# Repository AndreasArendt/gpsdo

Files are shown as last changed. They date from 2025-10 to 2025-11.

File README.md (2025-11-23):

# GPSDO

**GPSDO** (GPS Disciplined Oscillator) combines the precision of a high-quality OCXO (Oven-Controlled Crystal Oscillator) with the pulse-per-second (PPS) signal from a GNSS receiver. The goal is to achieve accurate time and frequency reference, down to the nanosecond level.

This project aims to create an **open-source and affordable** GPSDO from scratch, including designing custom hardware (PCB) and developing the supporting software.

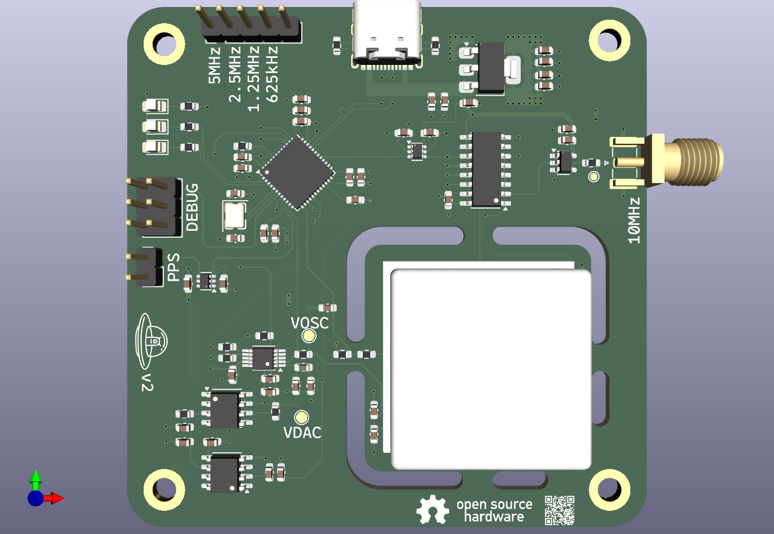
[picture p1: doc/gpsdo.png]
PCB v2 PCB Version 2


# Features
* Combines GNSS PPS with a high-precision OCXO
* Fully open-source hardware and software
* Targeting nanosecond-level timing precision
* Modular design for hardware and software development

# Status
🚧 Under Construction
* The first hardware prototype is currently being tested; all findings are documented in Issue #1
* A Kalman-Filter to estimate `phase`, `frequency_offset` and `frequency_drift` has been implemented
* A PI-Controller is running the GPSDO closed loop
* Flatbuf Messages are implemented to ensure easy-to-extend communication to a host system

# Roadmap
✅ Improve hardware based on findings from V2 prototype  
🔄 Integrate the GNSS receiver on-board for a fully standalone GPSDO  
⚙️ Fine-tune the control loop and filtering algorithms  
📊 Benchmark the true performance against reference standards  

# Contributing
Contributions are welcome! Whether it's hardware design suggestions, software improvements, or analysis scripts, feel free to open an issue or a pull request.

## Compiling flatcc (Windows)
* Navigate into `flatcc` submodule folder.  
* Create `build` folder
* Navigate into `build` folder
* Run `cmake ..`
* Run `cmake --build . --config Release`
* Executable is in `flatcc/bin/Release/flatcc.exe`

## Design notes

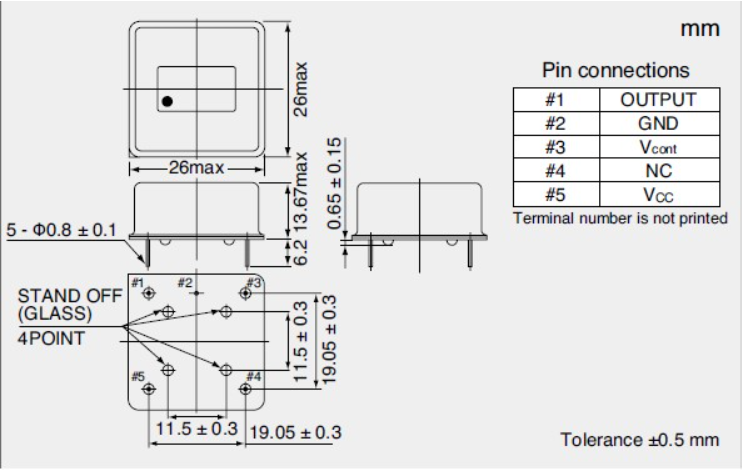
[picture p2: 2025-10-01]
doc/osc5a2b02/dimensions.png

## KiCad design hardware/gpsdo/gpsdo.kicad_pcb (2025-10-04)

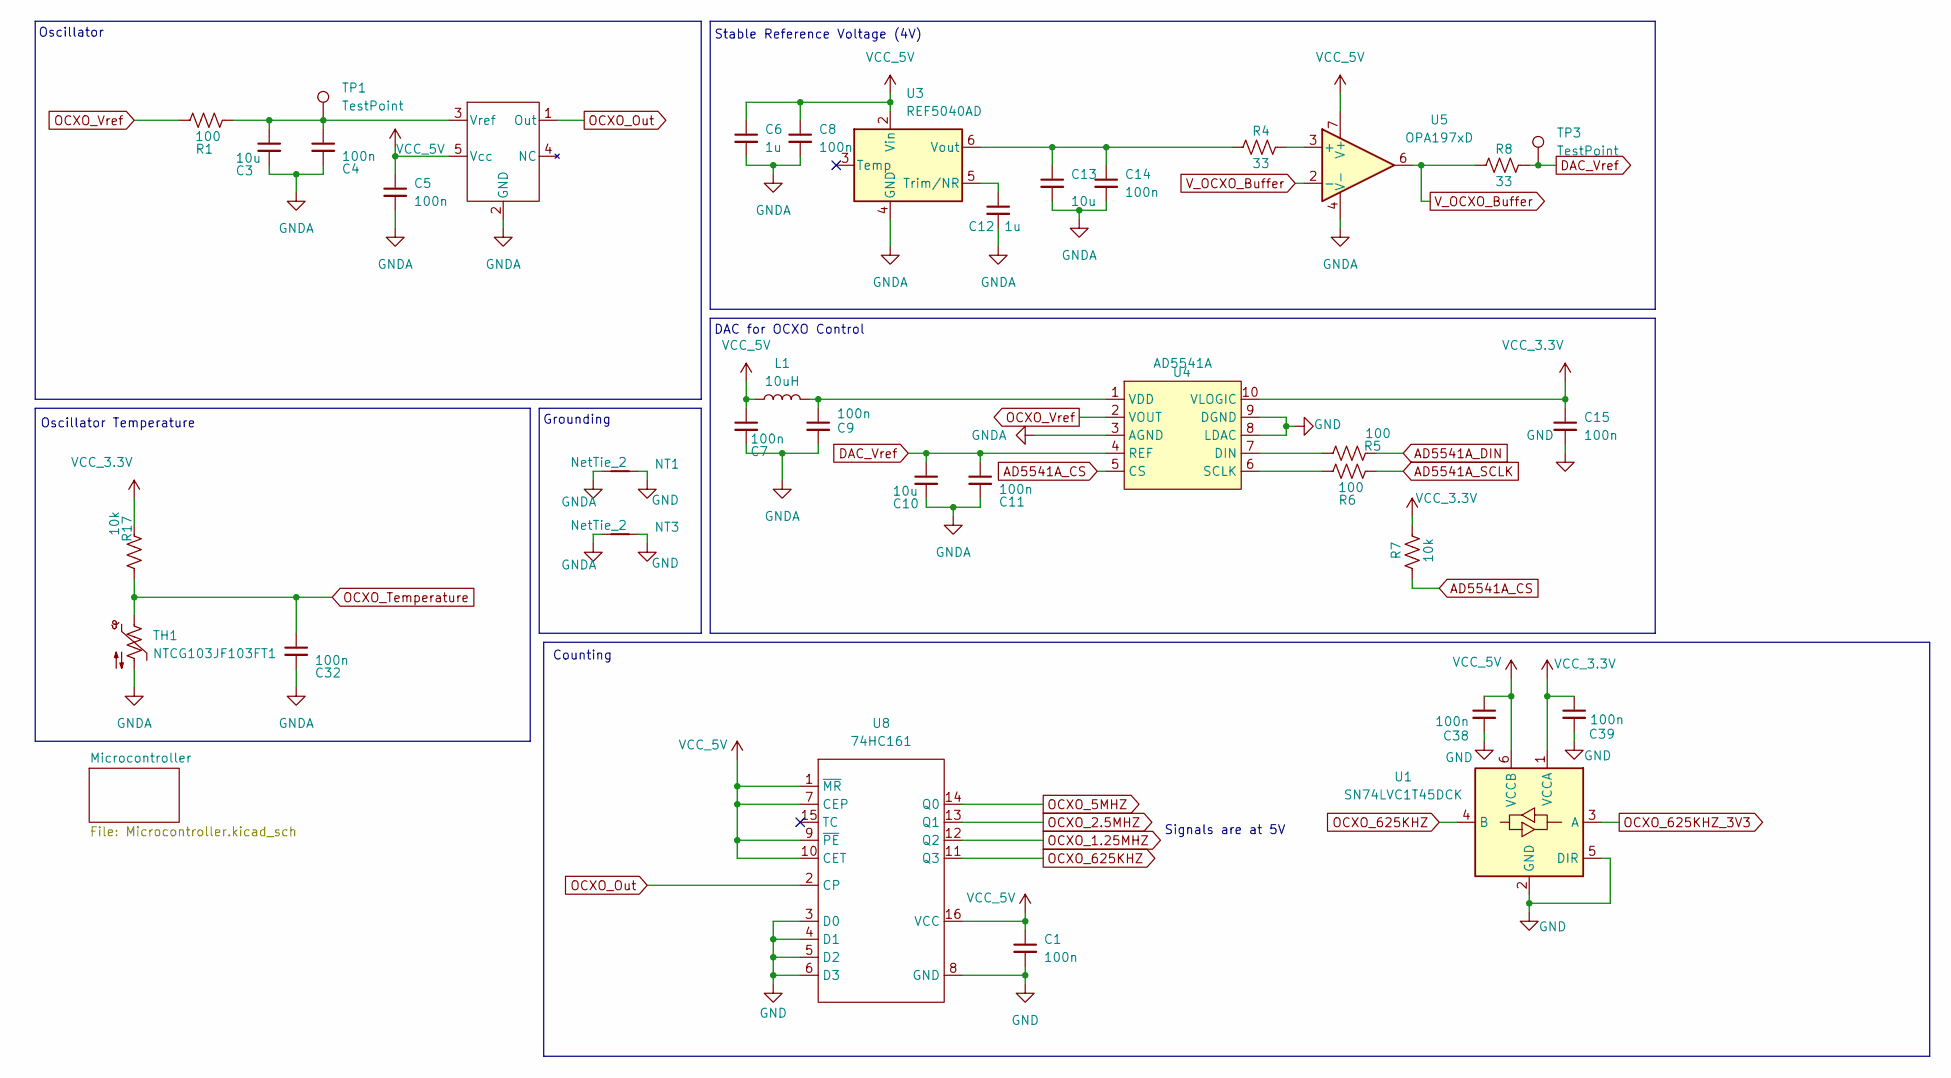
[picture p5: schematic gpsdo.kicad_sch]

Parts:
C1, C4, C5, C7, C8, C9, C11, C14, C15, C32, C38, C39: 100n; C_0603_1608Metric; JLC C14663
C3, C10, C13: 10u; C_0603_1608Metric; JLC C19702
C6, C12: 1u; C_0603_1608Metric; JLC C15849
L1: 10uH; L_0603_1608Metric; JLC C1035
NT1, NT3: NetTie_2; NetTie-2_THT_Pad0.3mm
OSC5A2B1: OSC5A2B02
R1, R5, R6: 100; R_0603_1608Metric; JLC C22775
R4, R8: 33; R_0603_1608Metric; JLC C23140
R7, R17: 10k; R_0603_1608Metric; JLC C25804
TH1: NTCG103JF103FT1; R_0603_1608Metric; JLC C209959
TP1, TP3: TestPoint; TestPoint_Pad_D1.5mm
U1: SN74LVC1T45DCK; SOT-363_SC-70-6; JLC C9382
U3: REF5040AD; SOIC-8_3.9x4.9mm_P1.27mm; JLC C1575304
U4: AD5541A; MSOP-10_3x3mm_P0.5mm; JLC C578210
U5: OPA197xD; SOIC-8_3.9x4.9mm_P1.27mm; JLC C79274
U8: 74HC161; SO-16_3.9x9.9mm_P1.27mm; JLC C22436995

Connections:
AD5541A_CS: R7.1, U4.5 (CS); also elsewhere on the board
AD5541A_DIN: R5.2; also elsewhere on the board
AD5541A_SCLK: R6.2; also elsewhere on the board
DAC_Vref: C10.1, C11.1, R8.2, TP3.1, U4.4 (REF)
GND: C1.2, C15.2, C38.2, C39.2, NT1.2, NT3.2, U1.2 (GND), U1.5 (DIR), U4.8 (LDAC), U4.9 (DGND), U8.3 (D0), U8.4 (D1), U8.5 (D2), U8.6 (D3), U8.8 (GND); also elsewhere on the board
GNDA: C3.2, C4.2, C5.2, C6.2, C7.2, C8.2, C9.2, C10.2, C11.2, C12.2, C13.2, C14.2, C32.2, NT1.1, NT3.1, OSC5A2B1.2 (GND), TH1.2, U3.4 (GND), U4.3 (AGND), U5.4 (V-); also elsewhere on the board
unnamed: C3.1, C4.1, OSC5A2B1.3 (Vref), R1.2, TP1.1
unnamed: C12.1, U3.5 (Trim/NR)
unnamed: C13.1, C14.1, R4.1, U3.6 (Vout)
unnamed: R5.1, U4.7 (DIN)
unnamed: R6.1, U4.6 (SCLK)
unnamed: C9.1, L1.2, U4.1 (VDD)
unnamed: R4.2, U5.3 (+)
OCXO_1.25MHZ: U8.12 (Q2); also elsewhere on the board
OCXO_2.5MHZ: U8.13 (Q1); also elsewhere on the board
OCXO_5MHZ: U8.14 (Q0); also elsewhere on the board
OCXO_625KHZ: U1.4 (B), U8.11 (Q3); also elsewhere on the board
OCXO_625KHZ_3V3: U1.3 (A); also elsewhere on the board
OCXO_Out: OSC5A2B1.1 (Out), U8.2 (CP); also elsewhere on the board
OCXO_Temperature: C32.1, R17.1, TH1.1; also elsewhere on the board
OCXO_Vref: R1.1, U4.2 (VOUT); also elsewhere on the board
VCC_5V: C1.1, C5.1, C6.1, C7.1, C8.1, C38.1, L1.1, OSC5A2B1.5 (Vcc), U1.6 (VCCB), U3.2 (Vin), U5.7 (V+), U8.1 (~MR), U8.7 (CEP), U8.9 (~PE), U8.10 (CET), U8.16 (VCC); also elsewhere on the board
VDD_3V3: C15.1, C39.1, R7.2, R17.2, U1.1 (VCCA), U4.10 (VLOGIC); also elsewhere on the board
V_OCXO_Buffer: R8.1, U5.2 (-), U5.6

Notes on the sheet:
Oscillator Temperature
Grounding
Stable Reference Voltage (4V)
Counting
Oscillator
DAC for OCXO Control
Signals are at 5V

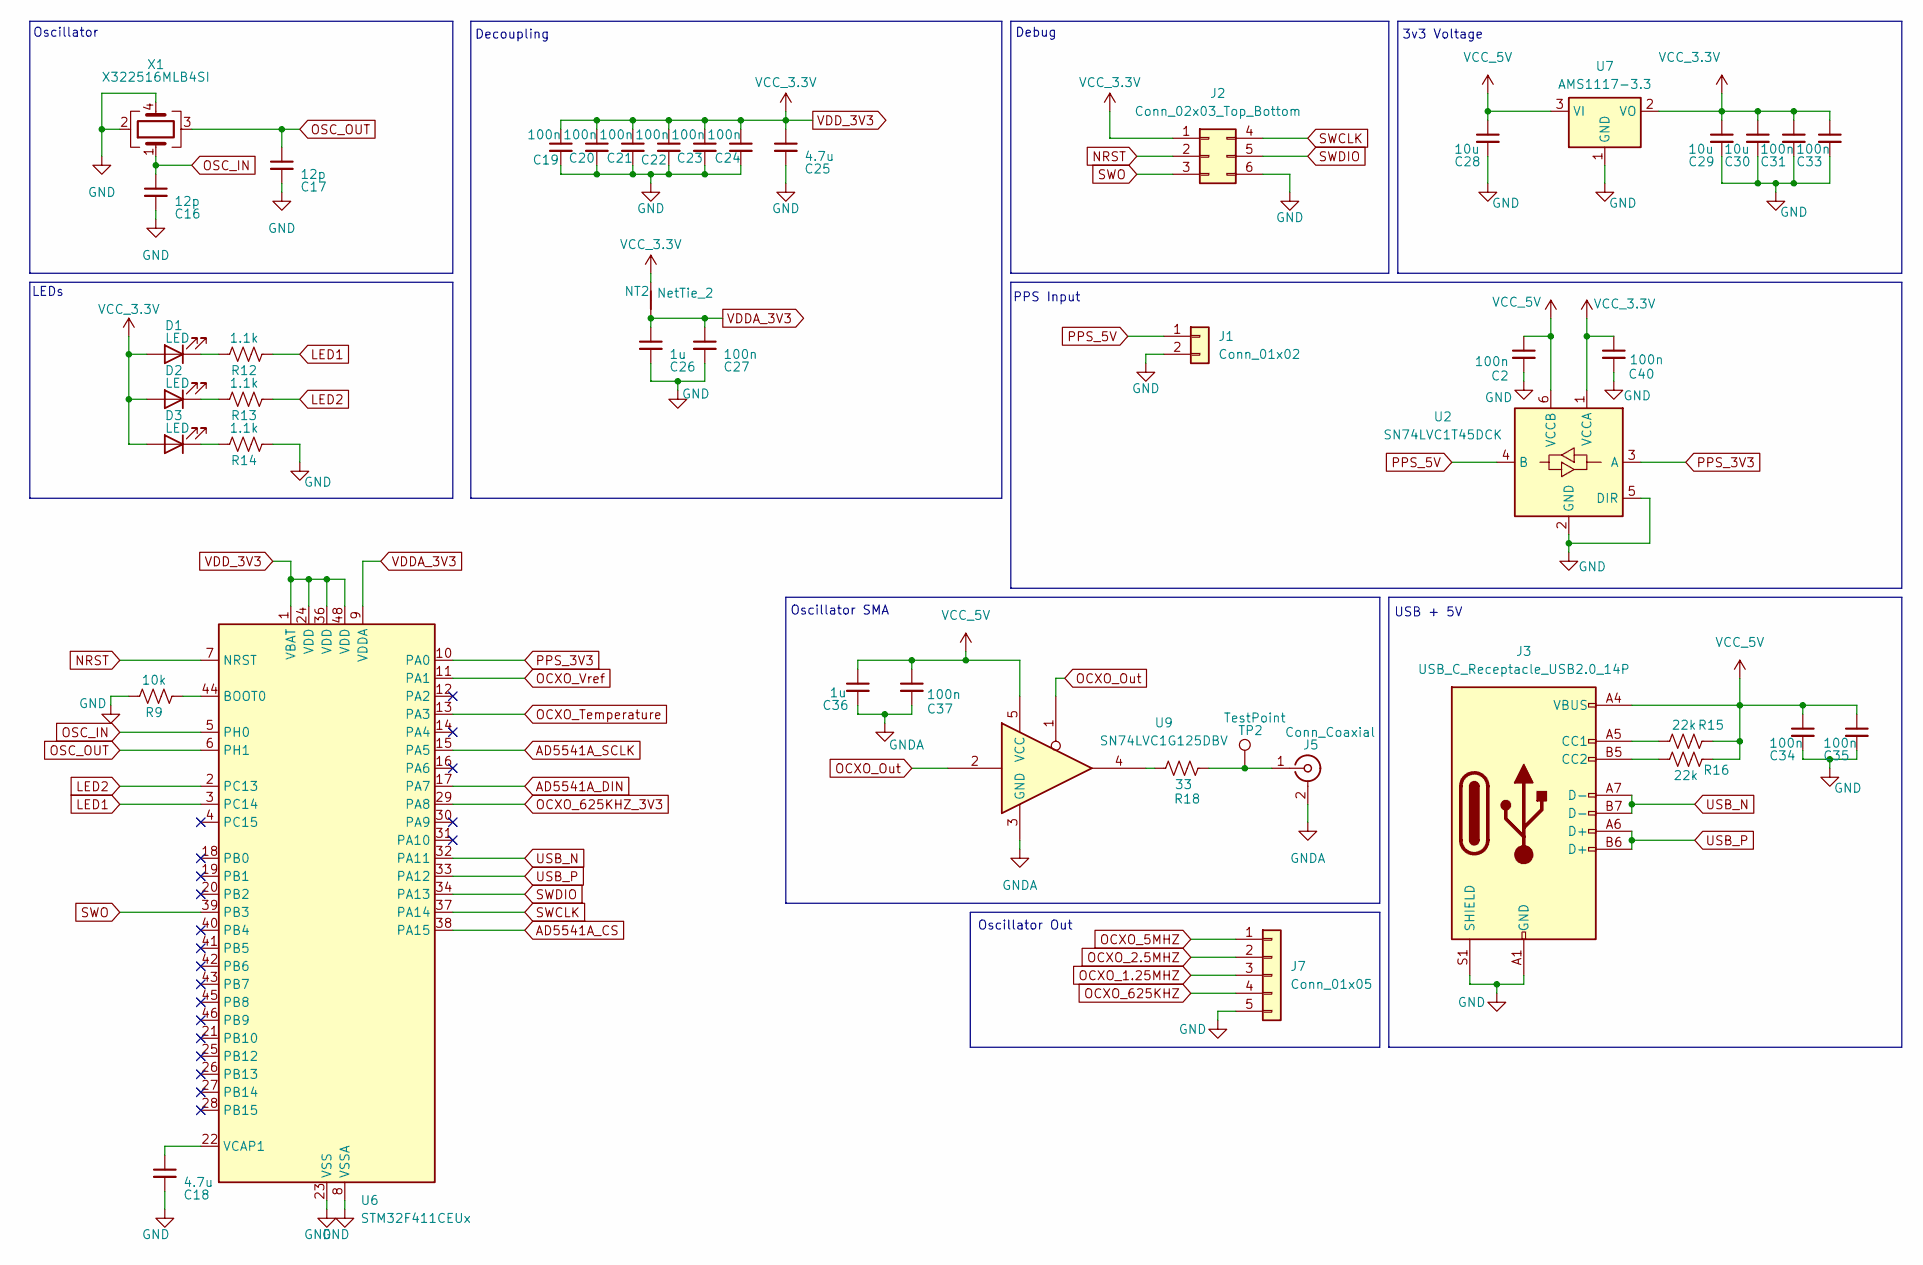
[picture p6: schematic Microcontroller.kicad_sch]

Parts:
C2, C19, C20, C21, C22, C23, C24, C27, C31, C33, C34, C35, C37, C40: 100n; C_0603_1608Metric; JLC C14663
C16, C17: 12p; C_0603_1608Metric; JLC C38523
C18, C25: 4.7u; C_0603_1608Metric; JLC C19666
C26, C36: 1u; C_0603_1608Metric; JLC C15849
C28, C29, C30: 10u; C_0603_1608Metric; JLC C19702
D1: LED; LED_0805_2012Metric_Pad1.15x1.40mm_HandSolder; JLC C2296
D2: LED; LED_0805_2012Metric_Pad1.15x1.40mm_HandSolder; JLC C84256
D3: LED; LED_0805_2012Metric_Pad1.15x1.40mm_HandSolder; JLC C2297
J1: Conn_01x02; PinHeader_1x02_P2.54mm_Vertical
J2: Conn_02x03_Top_Bottom; PinHeader_2x03_P2.54mm_Vertical
J3: USB_C_Receptacle_USB2.0_14P; USB_C_Receptacle_G-Switch_GT-USB-7010ASV; JLC C2988369
J5: Conn_Coaxial; SMA_Samtec_SMA-J-P-H-ST-EM1_EdgeMount; JLC C914558
J7: Conn_01x05; PinHeader_1x05_P2.54mm_Vertical
NT2: NetTie_2; NetTie-2_THT_Pad0.3mm
R9: 10k; R_0603_1608Metric; JLC C25804
R12, R13, R14: 1.1k; R_0603_1608Metric; JLC C17375
R15, R16: 22k; R_0603_1608Metric; JLC C31850
R18: 33; R_0603_1608Metric; JLC C23140
TP2: TestPoint; TestPoint_Pad_D1.0mm
U2: SN74LVC1T45DCK; SOT-363_SC-70-6; JLC C9382
U6: STM32F411CEUx; QFN-48-1EP_7x7mm_P0.5mm_EP5.6x5.6mm; JLC C60420
U7: AMS1117-3.3; SOT-223-3_TabPin2; JLC C347222
U9: SN74LVC1G125DBV; SOT-23-5; JLC C23654
X1: X322516MLB4SI; Crystal_SMD_3225-4Pin_3.2x2.5mm; JLC C13738

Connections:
AD5541A_CS: U6.38 (PA15); also elsewhere on the board
AD5541A_DIN: U6.17 (PA7); also elsewhere on the board
AD5541A_SCLK: U6.15 (PA5); also elsewhere on the board
GND: C2.2, C16.2, C17.2, C18.2, C19.2, C20.2, C21.2, C22.2, C23.2, C24.2, C25.2, C26.2, C27.2, C28.2, C29.2, C30.2, C31.2, C33.2, C34.2, C35.2, C40.2, J1.2, J2.6, J3.A1 (GND), J3.A12 (GND), J3.B1 (GND), J3.B12 (GND), J3.S1 (SHIELD), J7.5, R9.2, R14.1, U2.2 (GND), U2.5 (DIR), U6.8 (VSSA), U6.23 (VSS), U6.35 (VSS), U6.47 (VSS), U6.49 (VSS), U7.1 (GND), X1.2, X1.4; also elsewhere on the board
GNDA: C36.2, C37.2, J5.2 (Ext), U9.3 (GND); also elsewhere on the board
LED1: R12.1, U6.3 (PC14)
LED2: R13.1, U6.2 (PC13)
NRST: J2.2, U6.7 (NRST)
unnamed: D1.1 (K), R12.2
unnamed: D2.1 (K), R13.2
unnamed: D3.1 (K), R14.2
unnamed: J3.A5 (CC1), R15.2
unnamed: J3.B5 (CC2), R16.2
unnamed: J5.1 (In), R18.1, TP2.1
unnamed: R18.2, U9.4
unnamed: R9.1, U6.44 (BOOT0)
unnamed: C18.1, U6.22 (VCAP1)
OCXO_1.25MHZ: J7.3; also elsewhere on the board
OCXO_2.5MHZ: J7.2; also elsewhere on the board
OCXO_5MHZ: J7.1; also elsewhere on the board
OCXO_625KHZ: J7.4; also elsewhere on the board
OCXO_625KHZ_3V3: U6.29 (PA8); also elsewhere on the board
OCXO_Out: U9.1, U9.2; also elsewhere on the board
OCXO_Temperature: U6.13 (PA3); also elsewhere on the board
OCXO_Vref: U6.11 (PA1); also elsewhere on the board
OSC_IN: C16.1, U6.5 (PH0), X1.1
OSC_OUT: C17.1, U6.6 (PH1), X1.3
PPS_3V3: U2.3 (A), U6.10 (PA0)
PPS_5V: J1.1, U2.4 (B)
SWCLK: J2.4, U6.37 (PA14)
SWDIO: J2.5, U6.34 (PA13)
SWO: J2.3, U6.39 (PB3)
USB_N: J3.A7 (D-), J3.B7 (D-), U6.32 (PA11)
USB_P: J3.A6 (D+), J3.B6 (D+), U6.33 (PA12)
VCC_5V: C2.1, C28.1, C34.1, C35.1, C36.1, C37.1, J3.A4 (VBUS), J3.A9 (VBUS), J3.B4 (VBUS), J3.B9 (VBUS), R15.1, R16.1, U2.6 (VCCB), U7.3 (VI), U9.5 (VCC); also elsewhere on the board
VDDA_3V3: C26.1, C27.1, NT2.1, U6.9 (VDDA)
VDD_3V3: C19.1, C20.1, C21.1, C22.1, C23.1, C24.1, C25.1, C29.1, C30.1, C31.1, C33.1, C40.1, D1.2 (A), D2.2 (A), D3.2 (A), J2.1, NT2.2, U2.1 (VCCA), U6.1 (VBAT), U6.24 (VDD), U6.36 (VDD), U6.48 (VDD), U7.2 (VO); also elsewhere on the board

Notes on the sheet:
Oscillator Out
Debug
PPS Input
LEDs
USB + 5V
Oscillator SMA
Decoupling
3v3 Voltage
Oscillator

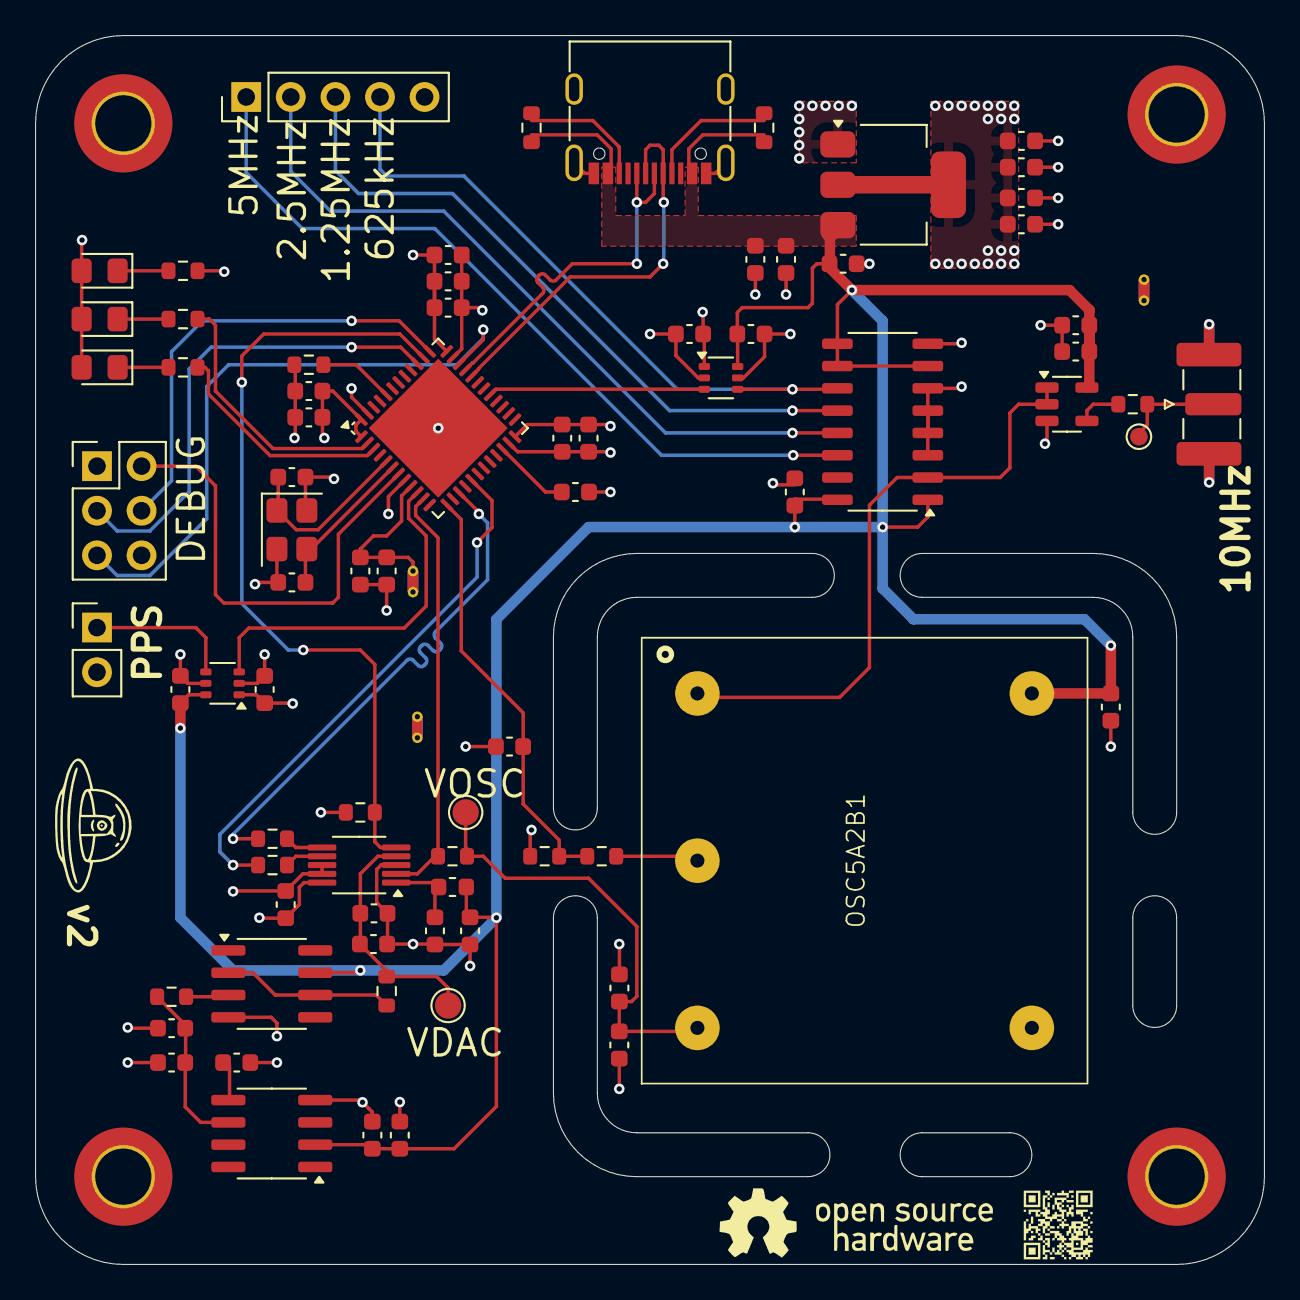
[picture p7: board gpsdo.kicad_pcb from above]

Board: 4 copper layers, 70.0 x 70.0 mm, 81 parts (0 on the bottom side), 46 nets.

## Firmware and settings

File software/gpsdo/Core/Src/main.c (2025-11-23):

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
/* Includes ------------------------------------------------------------------*/
#include "main.h"
#include "cmsis_os.h"
#include "usb_device.h"

/* USER CODE BEGIN Includes */
#include "pps.h"
#include "usb.h"
#include "led.h"
#include "hal.h"
/* USER CODE END Includes */

typedef StaticTask_t osStaticThreadDef_t;
typedef StaticSemaphore_t osStaticSemaphoreDef_t;
ADC_HandleTypeDef hadc1;
DMA_HandleTypeDef hdma_adc1;

SPI_HandleTypeDef hspi1;

TIM_HandleTypeDef htim1;
TIM_HandleTypeDef htim2;
TIM_HandleTypeDef htim5;

/* Definitions for tsk_controller */
osThreadId_t tsk_controllerHandle;
uint32_t controllerTaskBuffer[ 2048 ];
osStaticThreadDef_t controllerTaskControlBlock;
const osThreadAttr_t tsk_controller_attributes = {
  .name = "tsk_controller",
  .cb_mem = &controllerTaskControlBlock,
  .cb_size = sizeof(controllerTaskControlBlock),
  .stack_mem = &controllerTaskBuffer[0],
  .stack_size = sizeof(controllerTaskBuffer),
  .priority = (osPriority_t) osPriorityNormal,
};
/* Definitions for tsk_usb */
osThreadId_t tsk_usbHandle;
uint32_t usbTaskBuffer[ 2048 ];
osStaticThreadDef_t usbTaskControlBlock;
const osThreadAttr_t tsk_usb_attributes = {
  .name = "tsk_usb",
  .cb_mem = &usbTaskControlBlock,
  .cb_size = sizeof(usbTaskControlBlock),
  .stack_mem = &usbTaskBuffer[0],
  .stack_size = sizeof(usbTaskBuffer),
  .priority = (osPriority_t) osPriorityLow,
};
/* Definitions for tsk_manager */
osThreadId_t tsk_managerHandle;
uint32_t tsk_managerBuffer[ 256 ];
osStaticThreadDef_t tsk_managerControlBlock;
const osThreadAttr_t tsk_manager_attributes = {
  .name = "tsk_manager",
  .cb_mem = &tsk_managerControlBlock,
  .cb_size = sizeof(tsk_managerControlBlock),
  .stack_mem = &tsk_managerBuffer[0],
  .stack_size = sizeof(tsk_managerBuffer),
  .priority = (osPriority_t) osPriorityLow,
};
/* Definitions for xPPSSemaphore */
osSemaphoreId_t xPPSSemaphoreHandle;
osStaticSemaphoreDef_t xPPSSemaphoreControlBlock;
const osSemaphoreAttr_t xPPSSemaphore_attributes = {
  .name = "xPPSSemaphore",
  .cb_mem = &xPPSSemaphoreControlBlock,
  .cb_size = sizeof(xPPSSemaphoreControlBlock),
};
/* USER CODE BEGIN PV */
/* Definitions for sem_IMUdataReceived */
/* USER CODE END PV */

void SystemClock_Config(void);
static void MX_GPIO_Init(void);
static void MX_DMA_Init(void);
static void MX_TIM1_Init(void);
static void MX_TIM5_Init(void);
static void MX_ADC1_Init(void);
static void MX_TIM2_Init(void);
static void MX_SPI1_Init(void);
void controllerTask(void *argument);
void usbTask(void *argument);
void mangerTask(void *argument);

/* USER CODE BEGIN PFP */
uint8_t hal_initialized = 0;
/* USER CODE END PFP */

/* USER CODE BEGIN 0 */
uint16_t adc_dma_buffer[2];  // CH1, CH3
/* USER CODE END 0 */

/**
  * @brief  The application entry point.
  * @retval int
  */
int main(void)
{

  /* MCU Configuration--------------------------------------------------------*/

  /* Reset of all peripherals, Initializes the Flash interface and the Systick. */
  HAL_Init();

  /* Configure the system clock */
  SystemClock_Config();

  /* Initialize all configured peripherals */
  MX_GPIO_Init();
  MX_DMA_Init();
  MX_TIM1_Init();
  MX_TIM5_Init();
  MX_ADC1_Init();
  MX_TIM2_Init();
  MX_SPI1_Init();
  /* USER CODE BEGIN 2 */
	usb_init();

	HAL_NVIC_DisableIRQ(DMA2_Stream0_IRQn);  // disable ADC1 DMA interrupt
	HAL_ADC_Start_DMA(&hadc1, (uint32_t*) adc_dma_buffer, 2);

	reset_led_orange();
	reset_led_red();

  /* USER CODE END 2 */

  /* Init scheduler */
  osKernelInitialize();

  /* USER CODE BEGIN RTOS_MUTEX */
	/* add mutexes, ... */
  /* USER CODE END RTOS_MUTEX */

  /* Create the semaphores(s) */
  /* creation of xPPSSemaphore */
  xPPSSemaphoreHandle = osSemaphoreNew(1, 0, &xPPSSemaphore_attributes);

  /* USER CODE BEGIN RTOS_SEMAPHORES */
	/* add semaphores, ... */
  /* USER CODE END RTOS_SEMAPHORES */

  /* USER CODE BEGIN RTOS_TIMERS */
	/* start timers, add new ones, ... */
  /* USER CODE END RTOS_TIMERS */

  /* USER CODE BEGIN RTOS_QUEUES */
	/* add queues, ... */
  /* USER CODE END RTOS_QUEUES */

  /* Create the thread(s) */
  /* creation of tsk_controller */
  tsk_controllerHandle = osThreadNew(controllerTask, NULL, &tsk_controller_attributes);

  /* creation of tsk_usb */
  tsk_usbHandle = osThreadNew(usbTask, NULL, &tsk_usb_attributes);

  /* creation of tsk_manager */
  tsk_managerHandle = osThreadNew(mangerTask, NULL, &tsk_manager_attributes);

  /* USER CODE BEGIN RTOS_THREADS */
	/* add threads, ... */
  /* USER CODE END RTOS_THREADS */

  /* USER CODE BEGIN RTOS_EVENTS */
	/* add events, ... */
  /* USER CODE END RTOS_EVENTS */

  /* Start scheduler */
  osKernelStart();

  /* We should never get here as control is now taken by the scheduler */

  /* Infinite loop */
  /* USER CODE BEGIN WHILE */
	while (1) {

    /* USER CODE END WHILE */

    /* USER CODE BEGIN 3 */
	}
  /* USER CODE END 3 */
}

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
/* USER CODE BEGIN Header_controllerTask */
/**
 * @brief  Function implementing the tsk_controllerT thread.
 * @param  argument: Not used
 * @retval None
 */
/* USER CODE END Header_controllerTask */
__weak void controllerTask(void *argument)
{
  /* init code for USB_DEVICE */
  MX_USB_DEVICE_Init();
  /* USER CODE BEGIN 5 */
	/* Infinite loop */
	for (;;) {
		osDelay(1);
	}
  /* USER CODE END 5 */
}

/* USER CODE BEGIN Header_usbTask */
/**
 * @brief Function implementing the tsk_usb thread.
 * @param argument: Not used
 * @retval None
 */
/* USER CODE END Header_usbTask */
__weak void usbTask(void *argument)
{
  /* USER CODE BEGIN usbTask */
	/* Infinite loop */
	for (;;) {
		osDelay(1);
	}
  /* USER CODE END usbTask */
}

/* USER CODE BEGIN Header_mangerTask */
/**
 * @brief Function implementing the tsk_manager thread.
 * @param argument: Not used
 * @retval None
 */
/* USER CODE END Header_mangerTask */
__weak void mangerTask(void *argument)
{
  /* USER CODE BEGIN mangerTask */
	/* Infinite loop */
	for (;;) {
		osDelay(1);
	}
  /* USER CODE END mangerTask */
}

/**
  * @brief  Period elapsed callback in non blocking mode
  * @note   This function is called  when TIM4 interrupt took place, inside
  * HAL_TIM_IRQHandler(). It makes a direct call to HAL_IncTick() to increment
  * a global variable "uwTick" used as application time base.
  * @param  htim : TIM handle
  * @retval None
  */
void HAL_TIM_PeriodElapsedCallback(TIM_HandleTypeDef *htim)
{
  if (htim->Instance == TIM4)
  {
    HAL_IncTick();
  }
}

/**
  * @brief  This function is executed in case of error occurrence.
  * @retval None
  */
void Error_Handler(void)
{
  /* USER CODE BEGIN Error_Handler_Debug */
	/* User can add his own implementation to report the HAL error return state */
	__disable_irq();
	while (1) {
	}
  /* USER CODE END Error_Handler_Debug */
}
#ifdef USE_FULL_ASSERT
/**
  * @brief  Reports the name of the source file and the source line number
  *         where the assert_param error has occurred.
  * @param  file: pointer to the source file name
  * @param  line: assert_param error line source number
  * @retval None
  */
void assert_failed(uint8_t *file, uint32_t line)
{
  /* USER CODE BEGIN 6 */
  /* User can add his own implementation to report the file name and line number,
     ex: printf("Wrong parameters value: file %s on line %d\r\n", file, line) */
  /* USER CODE END 6 */
}
#endif /* USE_FULL_ASSERT */

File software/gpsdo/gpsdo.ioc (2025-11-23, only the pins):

Mcu.UserName=STM32F411CEUx
PA0-WKUP.Signal=S_TIM5_CH1
PA1.Signal=ADCx_IN1
PA11.Signal=USB_OTG_FS_DM
PA12.Signal=USB_OTG_FS_DP
PA13.Signal=SYS_JTMS-SWDIO
PA14.Signal=SYS_JTCK-SWCLK
PA15.Signal=GPIO_Output
PA3.Signal=ADCx_IN3
PA5.Signal=SPI1_SCK
PA7.Signal=SPI1_MOSI
PA8.Signal=S_TIM1_CH1
PB3.Signal=SYS_JTDO-SWO
PC13-ANTI_TAMP.Signal=GPIO_Output
PC14-OSC32_IN.Signal=GPIO_Output

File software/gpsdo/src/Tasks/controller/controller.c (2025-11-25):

#include "controller.h"
#include "hal.h"
#include "led.h"
#include "filter.h"
#include "pps.h"
#include "flatbuf_message_builder.h"
#include "manager.h"
#include "gpsdo_config.h"

#include <math.h>
#include <stdbool.h>

#define DAC_CS_Pin GPIO_PIN_15
#define DAC_CS_GPIO_Port GPIOA

#define DAC_SYNC_PORT GPIOA
#define DAC_SYNC_PIN GPIO_PIN_15

static const float Kp = 0.0025f;
static const float Ki = 0.00001f;
static const float Kd = 0.0f;

static KF_DebugSnapshot kf_debug = { 0 };

void DAC_Select() {
	HAL_GPIO_WritePin(DAC_CS_GPIO_Port, DAC_CS_Pin, GPIO_PIN_RESET);
}
void DAC_Unselect() {
	HAL_GPIO_WritePin(DAC_CS_GPIO_Port, DAC_CS_Pin, GPIO_PIN_SET);
}

void DAC_AD5541A_set_value(uint16_t value) {
	if (value >= 48000)
		return;

	uint8_t txData[2];

	// Split into bytes (MSB first)
	txData[0] = (value >> 8) & 0xFF;
	txData[1] = value & 0xFF;

	// Latch sequence
	HAL_GPIO_WritePin(DAC_SYNC_PORT, DAC_SYNC_PIN, GPIO_PIN_RESET);
	__NOP();
	__NOP();
	HAL_SPI_Transmit(&hspi1, txData, 2, HAL_MAX_DELAY);
	__NOP();
	__NOP();
	HAL_GPIO_WritePin(DAC_SYNC_PORT, DAC_SYNC_PIN, GPIO_PIN_SET);
}

void DAC_SetVoltage(float voltage) {
	// Clamp and scale
	if (voltage < V_Min)
		voltage = V_Min;
	if (voltage > V_Max)
		voltage = V_Max;

	uint16_t value = (uint16_t) roundf((voltage / DAC_VREF) * 65535.0f);
	DAC_AD5541A_set_value(value);
}

float control(float phase_cnt, float freq_offset, float freq_drift) {
	float p = Kp * freq_offset;
	float i = Ki * phase_cnt;
	float d = Kd * freq_drift;

	float v_out = V_Mid + p + i + d;

	// clamping
	if (v_out > V_Max)
		v_out = V_Max;
	if (v_out < V_Min)
		v_out = V_Min;

	return v_out;
}

float controller_ema(float val, float prev, float alpha) {
	return alpha * val + (1 - alpha) * prev;
}

void controllerTask(void *argument) {
	while (!hal_initialized)
		osDelay(100);

	static float volt = V_Mid;
	static float freq_drift_HzDs_prev = 0.0f, prev_phase = 0.0f, prev_freq = 0.0f;
	static bool first_run = true;

	filter_init();
	DAC_SetVoltage(volt);

	while (1) {
		osSemaphoreAcquire(xPPSSemaphoreHandle, osWaitForever);
		toggle_led_orange();
		uint32_t delta = pps_get_delta();

		filter_step(delta, volt);
		float phase_cnt = filter_get_phase_count();
		float freq_off_Hz = filter_get_frequency_offset_Hz();
		float freq_drift_HzDs = filter_get_frequency_drift_HzDs();

		// ema smoothing
		if(first_run)
			first_run = false;
		else
		{
			phase_cnt = controller_ema(phase_cnt, prev_phase, 0.02);       // 50 s
			freq_off_Hz = controller_ema(freq_off_Hz, prev_freq, 0.01);    // 100 s
			freq_drift_HzDs = controller_ema(freq_drift_HzDs, freq_drift_HzDs_prev, 0.001); // 1000s
		}

		freq_drift_HzDs_prev = freq_drift_HzDs;
		prev_phase = phase_cnt;
		prev_freq = freq_off_Hz;

		volt = control(-phase_cnt, -freq_off_Hz, -freq_drift_HzDs);
		//DAC_SetVoltage(volt);

		// sent flatbuf
		flatbuf_send_status(phase_cnt, freq_off_Hz, freq_drift_HzDs, volt,
				get_volt_meas(), get_temperature(), delta);
		filter_get_kf_debug_flatbuf(&kf_debug);
		flatbuf_send_kf_debug(&kf_debug);
	}
}

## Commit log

2025-09-06 starting pcb
    [gpsdo.kicad_pcb, gpsdo.kicad_sch]
2025-09-07 add i2c for ad5639; generate sine
2025-09-07 update hardware
    [gpsdo.kicad_sch]
2025-09-09 update schematics
    [gpsdo.kicad_sch]
2025-09-09 cleanup schematics
    [gpsdo.kicad_sch]
2025-09-29 update pcb; update hal
    [Microcontroller.kicad_sch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]
2025-09-30 update hal; update schematics and routing
    [Microcontroller.kicad_sch, gpsdo.kicad_pcb, gpsdo.kicad_sch]
2025-10-01 update routing
    [Microcontroller.kicad_sch, gpsdo.kicad_pcb, gpsdo.kicad_sch]
2025-10-01 add symbols to pcb
    [gpsdo.kicad_pcb]
2025-10-01 cleanup pcb
    [gpsdo.kicad_pcb]
2025-10-01 add qr code
    [gpsdo.kicad_pcb]
2025-10-01 bugfixing and fine tuning
    [gpsdo.kicad_pcb]
2025-10-01 final changes
    [gpsdo.kicad_pcb]
2025-10-01 cleanup; remove references from silkscreen
    [gpsdo-B_Cu.gbr, gpsdo-B_Mask.gbr, gpsdo-B_Paste.gbr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]
2025-10-01 update pcb
    [gpsdo.kicad_pcb]
2025-10-01 create first prod files
    [gpsdo-B_Cu.gbr, gpsdo-B_Mask.gbr, gpsdo-B_Paste.gbr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]
2025-10-02 final ratsnest
    [gpsdo.kicad_pcb]
2025-10-02 update routing; bugfix in downsampling; replace voltage dividers with level shifter
    [Microcontroller.kicad_sch, gpsdo.kicad_pcb, gpsdo.kicad_sch]
2025-10-02 update layout
    [gpsdo.kicad_pcb]
2025-10-02 bugfix in bom
    [Microcontroller.kicad_sch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]
2025-10-02 version 1 put into production
    [gpsdo-B_Cu.gbr, gpsdo-B_Mask.gbr, gpsdo-B_Paste.gbr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]
2025-10-04 revisit footprints
    [Microcontroller.kicad_sch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]
2025-10-17 configuration to count pulses between pps
    [gpsdo Debug.cfg]
2025-10-19 add kalman filter for frequency error and frequency error drift estimation
    [app.py, kalman.py, reader.py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]
2025-10-25 rework usb with queue for sending from any task
    [gpsdo.ioc, main.c, manager.c]
2025-10-25 implementation of adc
2025-10-27 fix spi; voltage setting not working exactly, but close
    [controller.c, gpsdo.ioc, main.c]
2025-10-28 fix spi mode
2025-10-28 Implementation of leds
2025-10-28 implement led blinking with pps
2025-10-29 add possibility to postprocess kalman filter
2025-10-29 re-tune kalman filter; adjust postprocessing
2025-10-29 kalman filter tweaking
2025-11-08 rework usb driver; add kalman filter
    [controller.c, filter.c, gpsdo.ioc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]
2025-11-08 cleanup, disable driver, add logging for stack overflows
2025-11-08 add sanity checking for filter value
2025-11-08 cleanup filter; add exponential smoothing
2025-11-08 cleanup timer isr
2025-11-08 adjust jitter filter; always output data for debugging
    [controller.c, filter.c]
2025-11-12 strip down pp kalman filter
2025-11-12 extend kalman filter to three states
2025-11-13 rewrite kalman filter - fixes #6
    [controller.c, filter.c]
2025-11-13 update filter
2025-11-22 align filter on python and c code side
2025-11-23 retune pid; adjust postprocessing scripts
2025-11-23 switch towards full static flatbuf implementation; reduce heap memory; update controller; add ema smoothing

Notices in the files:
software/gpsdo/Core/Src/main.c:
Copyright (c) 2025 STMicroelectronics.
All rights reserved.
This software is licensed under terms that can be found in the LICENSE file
